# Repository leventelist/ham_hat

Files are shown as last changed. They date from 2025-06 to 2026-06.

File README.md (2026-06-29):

# Raspberry PI hat for radio amateurs

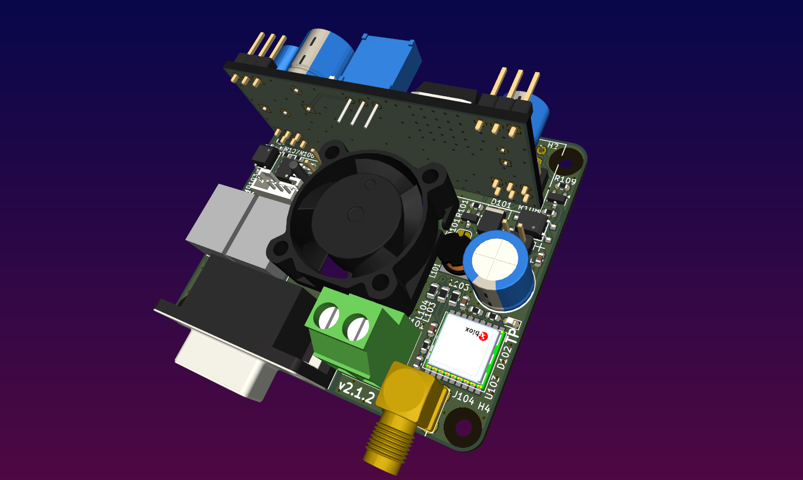
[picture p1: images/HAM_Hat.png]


## History

I've been doing a lot of SOTA activations with Raspberry PI like SBCs, and there
where always issues, like RF interference, and power supply shorts. I started to
add things like galvanically decoupled audio interface, a step down power supply. It
was working, but it looked like a mess.

This piece of hardware integrates all needed equipment in one nice hat. It is designed
to put the RPI in a metallic box to further isolate from RF signals.

It was designed using [KiCad](https://www.kicad.org/).

## Applications

* HF/VHF digital modes (PSK, FT8, etc)
* HF/VHF AX.25 based modes (Packet, APRS, etc)
* CW keying
* Clock synchronization
* Position tracking

## Features

 * 3A power supply with wide input voltage range: 8 to 35V
 * Ublox MAX-8/10 GPS receiver for position and time synchronization
 * Inductive audio couplers to minimize GND loops. Up to 4kHz.
 * PWM controlled cooling fan
 * GPIO controlled PTT from the PI
 * GPIO controlled CW key from the PI
 * RTC
 * Shutdown button
 * Run LED

GPS antenna is not integrated in the device, so an external antenna connector is
mounted on the PCB.

Ufortunately, the sound card of the PI can not record audio, so an
external sound card must be used. I use
[this](https://www.axagon.eu/en/produkty/ada-17) particular device with good
results. I usually break the plastic housing, and solder a shielded cable
directly to the audio interface (J109).

The GPS is needed for APRS and time synchronization. There is an onbard RTC to have some redundancy.

## Placing variants

There are a few components that mounted or unmounted depending on particular application.

### HT radio

When this device is used with a handheld radio, that has a PTT and mic input (Like the FT-4X), mount C108 and R116. Please note that the value of R116 might vary based on the actual transceiver used.

If used with a radio that has separate input for audio and PTT, mount a 0 Ohm resistor to C108. You might also leave C108 as a capacitor (22uF), but it is not really needed.

C108 and R116 is placed on the layout that it can be mounted or replaced after everything else is mounted too. All you need is the dismount tha cooling fan.

### High bandwidth audio

If you want to have direct access to the audio interface of your radio, you can leave T101 and T102 unpopulated and short JP102 and JP103, JP104. Please note that you will loose GND separation as well.

## Mechanics

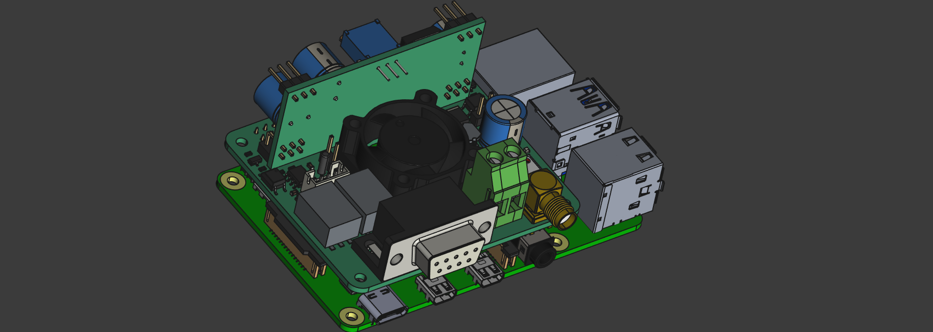
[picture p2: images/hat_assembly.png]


It is designed to fit on the Raspberry PI 4. Be aware, that if the heatsink on the CPU is too high, it might
conflict with the screws of the fan. If that happens, mount the heatsink 45 degrees.

### Box

A box is designed in FreeCAD using sheets of PCB. The idea is to use bare, one sided PCBs, and solder the plates from the inside. The sheets can be easily milled by a CNC machine.

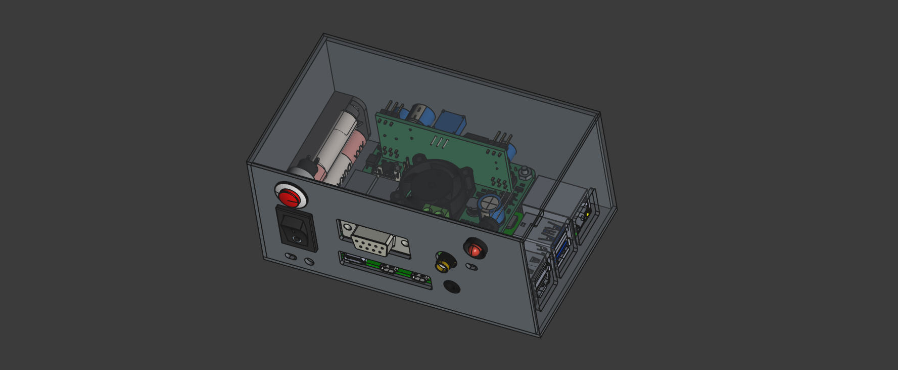
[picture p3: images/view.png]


There are several cutouts on the box.

In the front, you have the power inlet, and a second cutout for powering the attached LCD screen. On the right side of the front sheet, there is a cutout for the power chord to the GPS antenna, if needed.

On the right, there are anouther cutout for the audio cable.

The assembly does not include some (all) the models, hence they might violate copyright.

## Connection to the radio

The hat comes with a DB9 connector to connect up your rig. I wanted to have a screw lock
connector, and this was the best choice. The pin out looks like this.

| Signal name | Pin of the DB9 | Comment |
|---|---|---|
| TX audio | 1 | Audio input of your rig  |
| KEY | 2 | CW key of the rig |
| PTT | 3 | PTT input of your rig |
| NC | 4 | Not connected |
| RX audio | 5 | Audio output of your rig |
| GND | 6 | Audio ground |
| GND | 7 | Audio ground |
| GND | 8 | Audio ground |
| GND | 9 | Audio ground |

### GPIO connections

| Signal name | GPIO | Commnet |
|---|---|---|
| PTT | 12 | |
| KEY | 21 | |
| DCD | 16 | |

## Connection to the soundcard

J105 provides connection to the soundcard.

| Signal name | Pin of J105 | Comment |
|---|---|---|
| RX audio | 1 | Mic input of your soundcard |
| TX audio | 4 | Speaker output of your soundcard |
| GND | 2,3 | Audio ground |

## Power connection

J101 provides power connection. The maximum input voltage is 35Volts.

## GPS

Use u-blox MAX-8C/Q or MAX-M10S GNSS module. When the MAX-10 is used, don't populate R113.

Connect your passive or active GPS antenna to J104. Use 3.3V active antenna. PPS signal is provided on GPIO18.

When passive antenna is used, don't populate L102.

[Here](https://austinsnerdythings.com/2021/04/19/microsecond-accurate-ntp-with-a-raspberry-pi-and-pps-gps/) is an excellent article how to set up GPIO-PPS for ntpd.

## RTC

BQ32000 based precision RTC is provided for backup if the GPS can't provide accurate timing.

### Enable I²C on Raspberry Pi
```bash
sudo raspi-config
```
Navigate to:
```
Interfacing Options → I2C → Enable
```
Reboot the Raspberry Pi:
```bash
sudo reboot
```

### Check I²C Communication
```bash
sudo apt install i2c-tools
i2cdetect -y 1
```
You should see the RTC at **0x68**.

### Configure Linux to Use BQ32000
```bash
sudo modprobe rtc-bq32k
echo bq32000 0x68 | sudo tee /sys/class/i2c-dev/i2c-1/device/new_device

# This next one line only needed to set initial time of the RTC
# Otherwise it'll fail to read
sudo hwclock -w

# Test to read the RTC
sudo hwclock -r
```

### Make It Persistent
Edit `/boot/firmware/config.txt`:

Add the following line:
```
dtoverlay=i2c-rtc,bq32000
```
Save and reboot:
```bash
sudo reboot
```

### Disable Fake RTC (if needed)
```bash
sudo systemctl disable fake-hwclock
sudo systemctl stop fake-hwclock
```
Edit `/lib/udev/hwclock-set` and comment out:
```bash
#if [ -e /run/systemd/system ] ; then
#    exit 0
#fi
```
```bash
apt remove fake-hwclock
```

### Create a systemd service to set system clock from RTC

/etc/systemd/system/rtc-sync.service

The content of this file attached.

### Sync RTC with System Time
Set RTC from system time:
```bash
sudo hwclock -w
```
Set system time from RTC:
```bash
sudo hwclock -s
```

### Final Test
Check that the RTC retains the time after reboot:
```bash
sudo hwclock -r
```

Connect a 3V battery to BT101 for offline RTC operation.

## FAN control

PWM shall be enabled on GPIO13.

If you don't want PWM control, short JP101, and the fan will spin at full power all times.

There's a non-PWM control of the fan that works out of the box using the Raspberry PI OS.

Open raspi-config, under Performance Options, you shall select the desired temperature,
and the GPIO pin which is 13.

## Shutdown button can be connected to J106

To make it work, you have to add these lines to /boot/firmware/config,txt

```
dtoverlay=gpio-shutdown,gpio_pin=26
```

Ther's also a LED (D107 )that shines when the system is running. When it
Doesn't, it is safe to remove power from the RPI.

To make this work, add this too:

```
dtoverlay=gpio-poweroff,gpiopin=7,active_low=1
```

## Accessories

These items needed for the hat for full functionality.

All sourced from [Farnell](https://www.farnell.com/), unless othervise noted. (Sorry, I'm Hungary based.)

| Item | Source designator | Comment |
|---|---|---|
| RTC Battery | 1892670 | The idea is to use heatshrink tube and some wires. |
| RTC Battery holder | 3583203 | External battery holder for CR2032 |
| Heatsink | 1211701 or https://www.alza.hu/raspberry-pi-rb-hutoborda-d4147799.htm?o=21 ||
| Standoff | 1466844 | It must be 12mm in length |
| Mounting screws M2.5x6 | | |
| GPS antenna | [This](https://www.soselectronic.hu/products/2j/2j431gmp-250rg174-c20n-173902) or [this](https://www.soselectronic.hu/products/2j/2j0801b-c814g-217598) | Use 3V active antenna |
| RPI4 | 3369503 (8GB) or 3051887 (4GB) | |
| USB audio interface| [Alza](https://www.alza.hu/axagon-ada-10-mini-d1470921.htm) | Any other do the job. Check Linux driver availability. |
| Monitor| [Ebay](https://www.ebay.com/itm/353758771148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)
| Keyboard | https://www.pcland.hu/genius-luxemate-100-usb-fekete-hun-billentyuzet-31300725113 | Any USB Keyboard. I use the one without keypad, for its compact size. |
| Mice | | Any USB, or BLE mice |
| SD card with Raspbian image. | | |
| uHDMI to HDMI cable | [Alza](https://www.alza.hu/vention-micro-hdmi-to-hdmi-cable-2m-black-d5891200.htm?o=1) | |
| DB9 Male connector | | To connect to your radio |
| Data connector for your radio |
| Shielded audio cable | | To connect the soundcard to the hat, and for the DB9 connector |

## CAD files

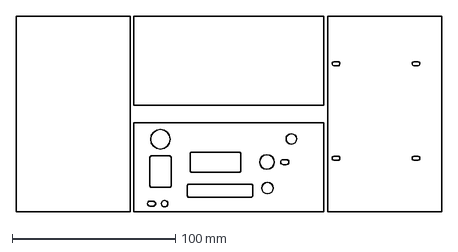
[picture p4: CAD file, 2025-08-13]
box/CNC/integrated/large_parts.dxf
261.0 x 120.0 mm

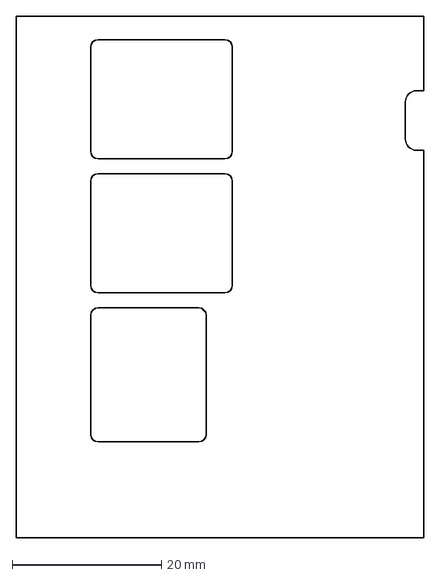
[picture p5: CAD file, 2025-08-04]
box/CNC/rpi4_case_base-right.dxf
54.7 x 70.0 mm

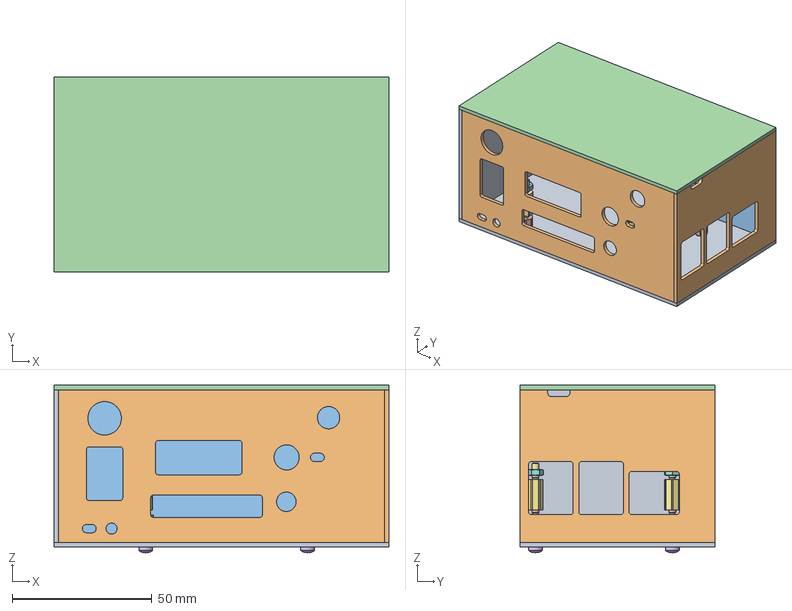
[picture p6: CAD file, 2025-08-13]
box/rpi4_case_base.FCStd
120.0 x 70.0 x 60.0 mm
base
front
back
top
M2.5x10x5-Standoff x 4
M2.5x6-Screw x 4
M2.5x11x5-Standoff x 4
M2.5-Nut x 4
left
right

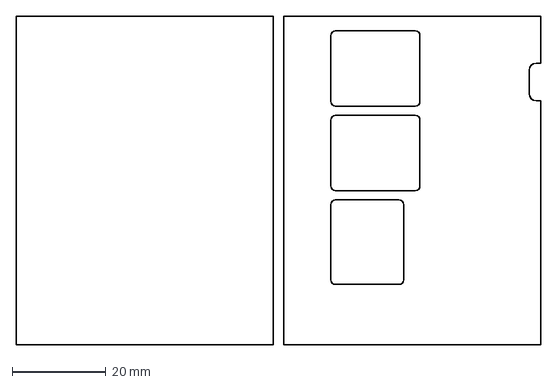
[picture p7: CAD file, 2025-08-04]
box/CNC/integrated/small_parts.dxf
111.7 x 70.0 mm

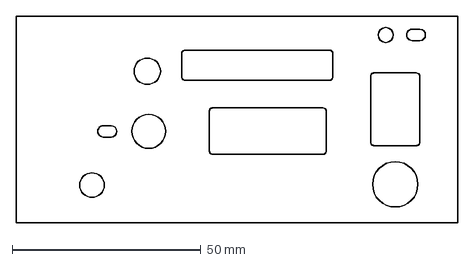
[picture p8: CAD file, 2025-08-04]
box/CNC/rpi4_case_base-front.dxf
116.7 x 54.7 mm

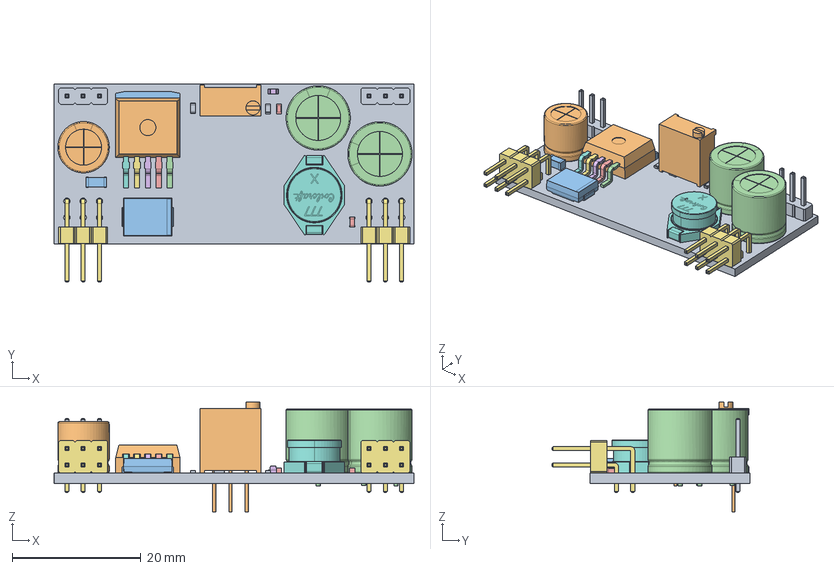
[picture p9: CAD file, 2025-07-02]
box/SMPS3A.FCStd
56.0 x 30.8 x 17.1 mm
Pcb_f4e0
C101_CP_Radial_D80mm_P350mm_00005b5bec9b
C102_C_1206_3216Metric_00005b5bed43
C103_CP_Radial_D100mm_P500mm_00005b5bed53 x 2
C104_C_0603_1608Metric_00005b5bee1e x 2
D102_LED_0603_1608Metric_00005b5bef20
J101_PinHeader_2x03_P254mm_Horizontal_00005b5bef32 x 2
L102_Coilcraft-DO3316P_00005b5befd3
R101_R_0603_1608Metric_00005b5befde x 3
a648ce37-9c39-11ed-93f0-dde97e994e83_part
a648ce38-9c39-11ed-93f0-dde97e994e83_part
a648ce39-9c39-11ed-93f0-dde97e994e83_part
a648ce39-9c39-11ed-93f0-dde97e994e83_part001
a648ce39-9c39-11ed-93f0-dde97e994e83_part002
a648ce39-9c39-11ed-93f0-dde97e994e83_part003
a648ce39-9c39-11ed-93f0-dde97e994e83_part004
J103_PinHeader_1x03_P254mm_Vertical_00005b5cb08c x 2
RV101_Potentiometer_Bourns_3296W_Vertical_00005fe729f7
D101_D_SMC_0000611d8a5b

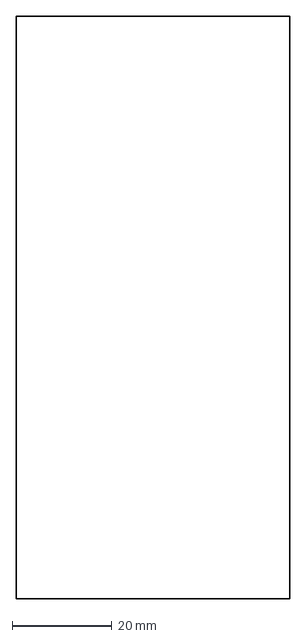
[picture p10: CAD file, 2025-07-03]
box/CNC/rpi4_case_base-back.dxf
54.7 x 116.7 mm

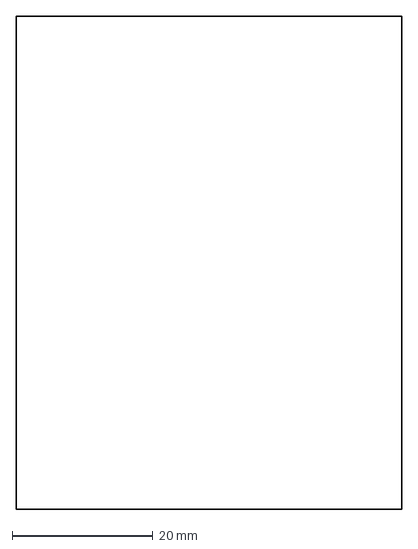
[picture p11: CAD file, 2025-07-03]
box/CNC/rpi4_case_base-left.dxf
54.7 x 70.0 mm

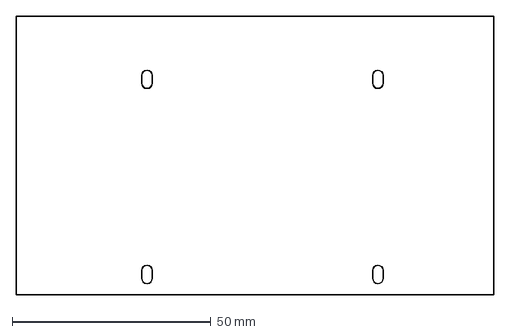
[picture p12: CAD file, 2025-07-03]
box/CNC/rpi4_case_base-base.dxf
120.0 x 70.0 mm

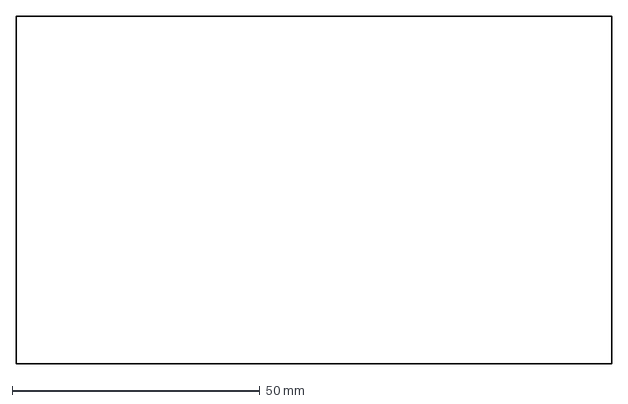
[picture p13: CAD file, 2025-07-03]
box/CNC/rpi4_case_base-top.dxf
120.0 x 70.0 mm

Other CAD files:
assembly/hat_assembly.FCStd

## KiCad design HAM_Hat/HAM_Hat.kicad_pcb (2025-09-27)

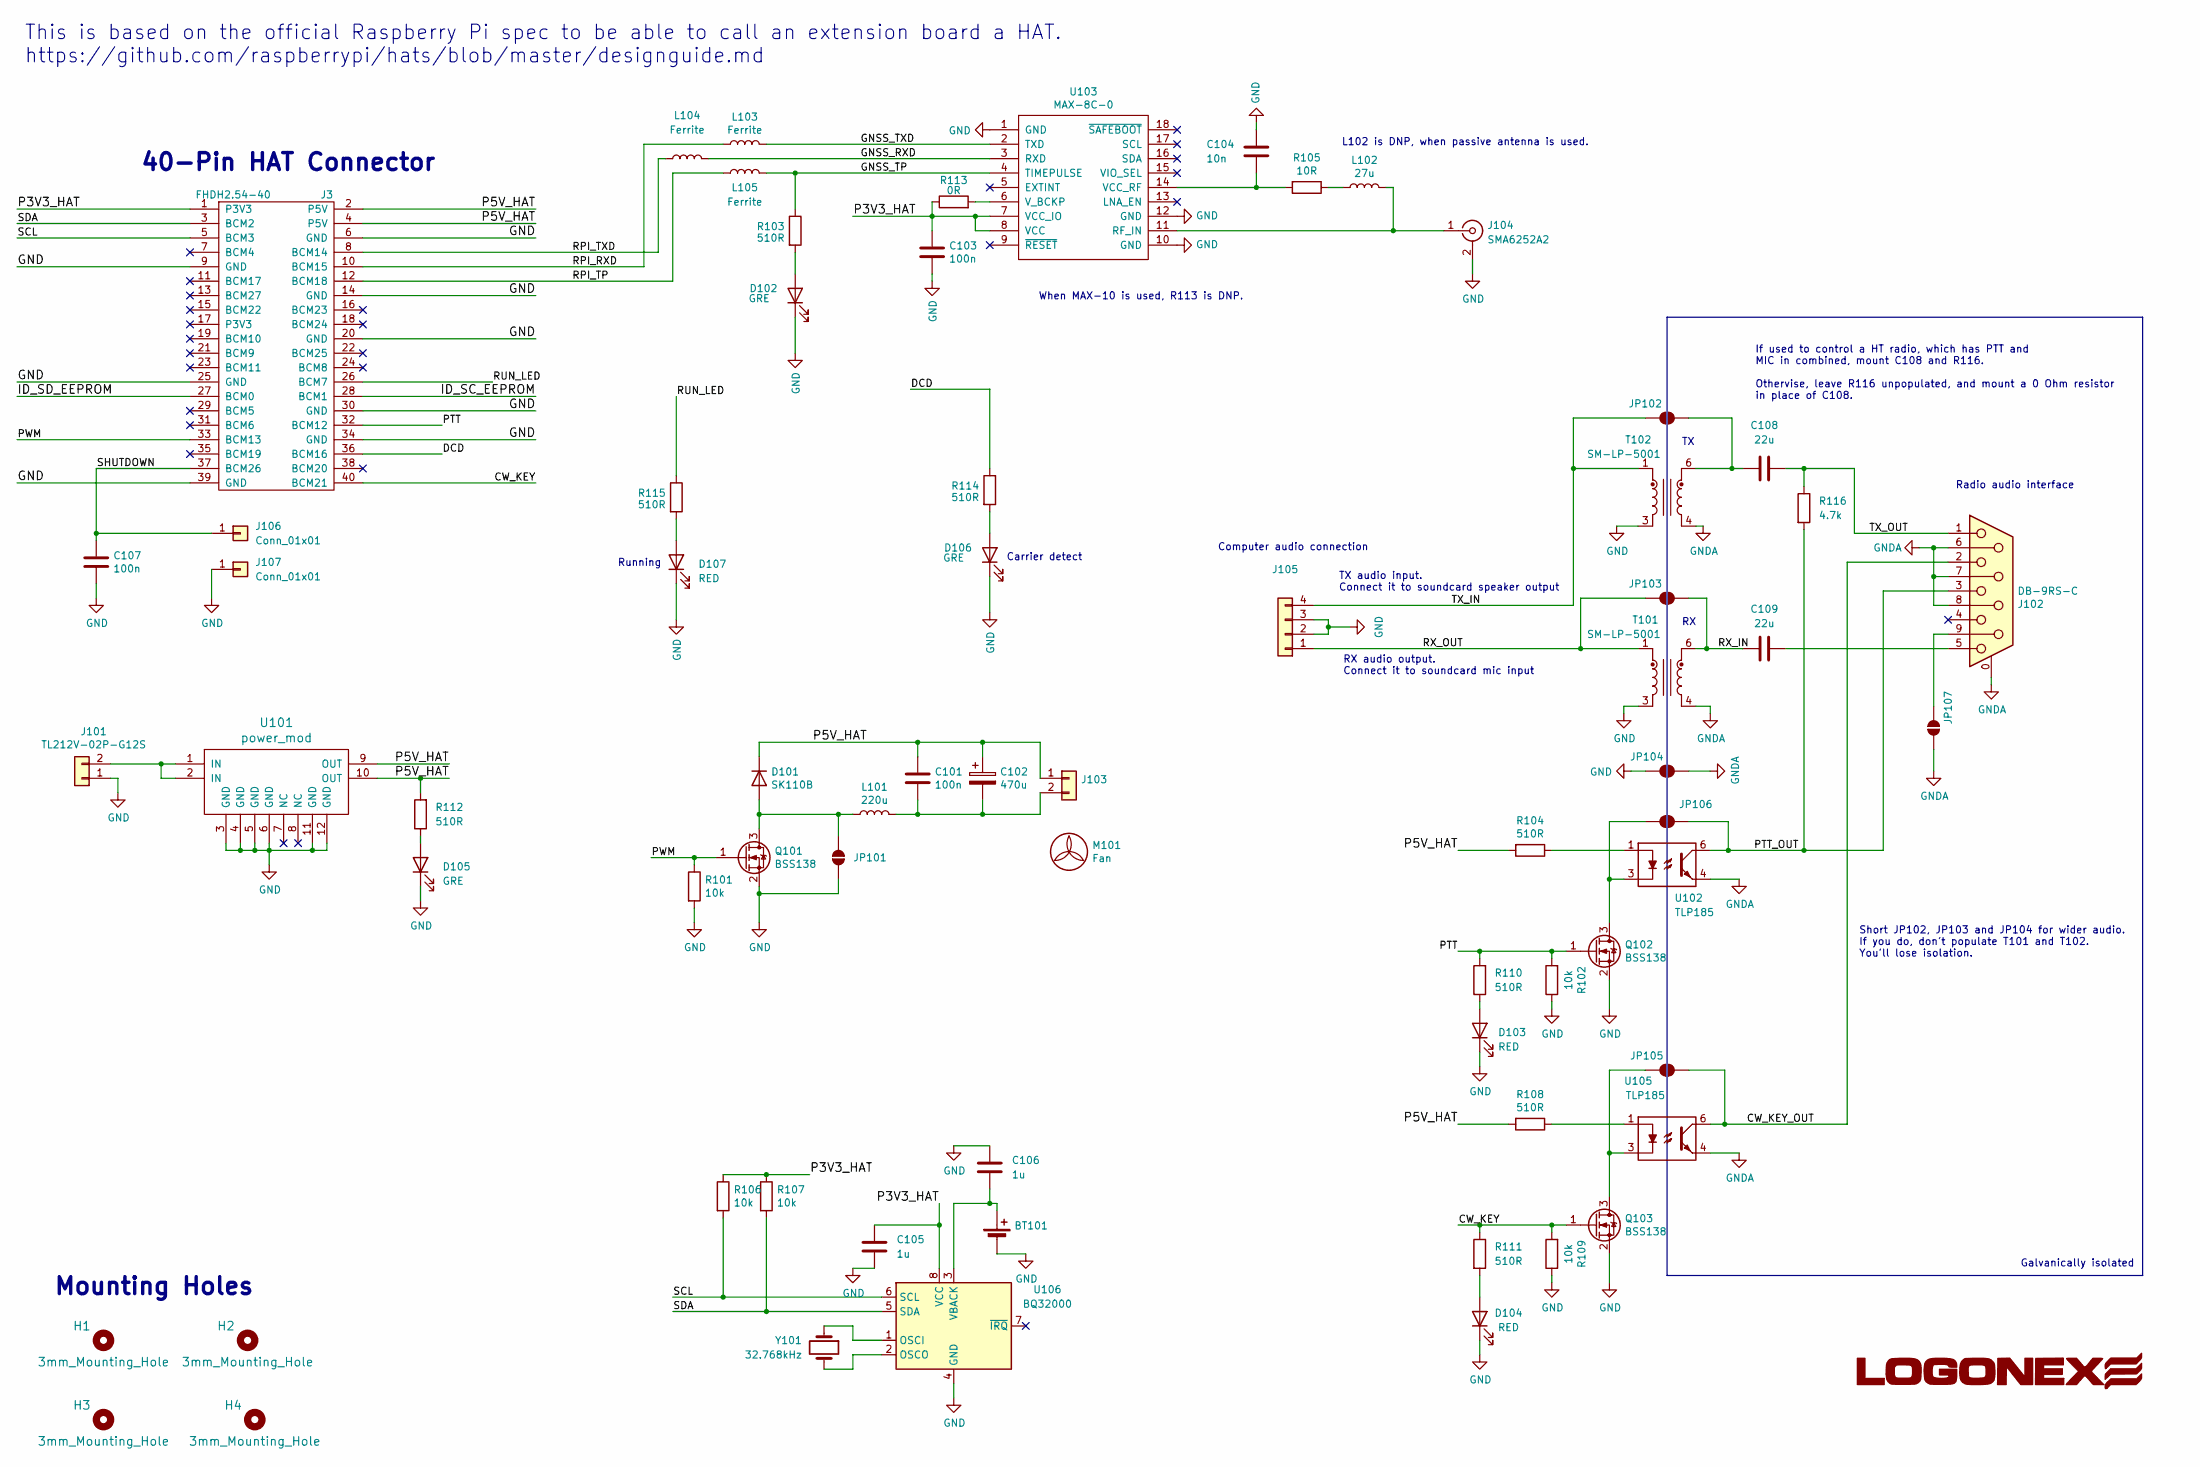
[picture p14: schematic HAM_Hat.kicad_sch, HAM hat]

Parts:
BT101: PinHeader_2x01_P2.54mm_Vertical
C101, C103, C107: 100n; C_0603_1608Metric
C102: 470u; CP_Radial_D10.0mm_P5.00mm
C104: 10n; C_0603_1608Metric
C105, C106: 1u; C_0603_1608Metric
C108, C109: 22u; C_1206_3216Metric
D101: SK110B; D_SMB
D102, D105, D106: GRE; LED_0603_1608Metric
D103, D104, D107: RED; LED_0603_1608Metric
H1, H2, H3, H4: 3mm_Mounting_Hole; l_MountingHole_Clear_2.75mm_M2.5
J3: FHDH2.54-40; PinSocket_2x20_P2.54mm_Vertical
J101: TL212V-02P-G12S; TerminalBlock-2-5.0_1x02_P5.0mm_Horizontal
J102: DB-9RS-C; DSUB-9_Female_Horizontal_P2.77x2.84mm_EdgePinOffset7.70mm_H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
J103: PinHeader_1x02_P2.54mm_Vertical
J104: SMA6252A2; SMA_angled
J105: PinHeader_1x04_P2.54mm_Vertical
J106, J107: Conn_01x01; SolderWirePad_1x01_SMD_2x5mm
JP101, JP102, JP103, JP104, JP105, JP106, JP107: SolderJumper_2_Open; SolderJumper-2_P1.3mm_Open_RoundedPad1.0x1.5mm
L101: 220u; IND_PCD0504
L102: 27u; L_0603_1608Metric
L103, L104, L105: Ferrite; R_0805_2012Metric
M101: Fan; 25x25
Q101, Q102, Q103: BSS138; SOT-23
R101, R102, R106, R107, R109: 10k; R_0603_1608Metric
R103, R104, R108, R110, R111, R112, R114, R115: 510R; R_0603_1608Metric
R105: 10R; R_0603_1608Metric
R113: 0R; R_0603_1608Metric
R116: 4.7k; R_0603_1608Metric
T101, T102: SM-LP-5001; SM_LP_5001
U101: power_mod; power_mod3A
U102, U105: TLP185; 11-4M1S
U103: MAX-8C-0; MAX8
U106: BQ32000; SOIC-8_3.9x4.9mm_P1.27mm
Y101: 32.768kHz; Crystal_DS26_D2.0mm_L6.0mm_Vertical

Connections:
/CW_KEY: J3.40 (BCM21), Q103.1 (G), R109.2, R111.1
/CW_KEY_OUT: J102.2, JP105.2 (B), U105.6
/DCD: J3.36 (BCM16), R114.1
/GNSS_RXD: L104.2, U103.3 (RXD)
/GNSS_TP: L105.2, R103.1, U103.4 (TIMEPULSE)
/GNSS_TXD: L103.2, U103.2 (TXD)
/ID_SC_EEPROM: J3.28 (BCM1)
/ID_SD_EEPROM: J3.27 (BCM0)
/P3V3_HAT: C103.1, C105.1, J3.1 (P3V3), R106.1, R107.1, R113.1, U103.7 (VCC_IO), U103.8 (VCC), U106.8 (VCC)
/P5V_HAT: C101.1, C102.1, D101.1 (K), J3.2 (P5V), J3.4 (P5V), J103.1, R104.2, R108.2, R112.2, U101.9 (OUT), U101.10 (OUT)
/PTT: J3.32 (BCM12), Q102.1 (G), R102.2, R110.2
/PTT_OUT: J102.3, JP106.2 (B), R116.2, U102.6
/PWM: J3.33 (BCM13), Q101.1 (G), R101.1
/RPI_RXD: J3.10 (BCM15), L103.1
/RPI_TP: J3.12 (BCM18), L105.1
/RPI_TXD: J3.8 (BCM14), L104.1
/RUN_LED: J3.26 (BCM7), R115.1
/RX_IN: C109.2, JP103.2 (B), T101.6
/RX_OUT: J105.1, JP103.1 (A), T101.1
/SCL: J3.5 (BCM3), R106.2, U106.6 (SCL)
/SDA: J3.3 (BCM2), R107.2, U106.5 (SDA)
/SHUTDOWN: C107.1, J3.37 (BCM26), J106.1
/TX_IN: J105.4, JP102.1 (A), T102.1
/TX_OUT: C108.2, J102.1, R116.1
GND: BT101.2 (-), C103.2, C104.1, C105.2, C106.1, C107.2, D102.1 (K), D103.1 (K), D104.1 (K), D105.1 (K), D106.1 (K), D107.1 (K), J3.6 (GND), J3.9 (GND), J3.14 (GND), J3.20 (GND), J3.25 (GND), J3.30 (GND), J3.34 (GND), J3.39 (GND), J101.1, J104.2 (Ext), J105.2, J105.3, J107.1, JP101.2 (B), JP104.1 (A), Q101.2 (S), Q102.2 (S), Q103.2 (S), R101.2, R102.1, R109.1, T101.3, T102.3, U101.3 (GND), U101.4 (GND), U101.5 (GND), U101.6 (GND), U101.11 (GND), U101.12 (GND), U103.1 (GND), U103.10 (GND), U103.12 (GND), U106.4 (GND)
GNDA: J102.0 (PAD), J102.6, J102.7, J102.8, JP104.2 (B), JP107.2 (B), T101.4, T102.4, U102.4, U105.4
unnamed: BT101.1 (+), C106.2, U106.3 (VBACK)
unnamed: C109.1, J102.5
unnamed: D101.2 (A), JP101.1 (A), L101.1, Q101.3 (D)
unnamed: D102.2 (A), R103.2
unnamed: D103.2 (A), R110.1
unnamed: D104.2 (A), R111.2
unnamed: D105.2 (A), R112.1
unnamed: D106.2 (A), R114.2
unnamed: D107.2 (A), R115.2
unnamed: J101.2, U101.1 (IN), U101.2 (IN)
unnamed: C101.2, C102.2, J103.2, L101.2
unnamed: J104.1 (In), L102.2, U103.11 (RF_IN)
unnamed: C108.1, JP102.2 (B), T102.6
unnamed: JP105.1 (A), Q103.3 (D), U105.3
unnamed: JP106.1 (A), Q102.3 (D), U102.3
unnamed: J102.9, JP107.1 (A)
unnamed: L102.1, R105.1
unnamed: R104.1, U102.1
unnamed: R108.1, U105.1
unnamed: C104.2, R105.2, U103.14 (VCC_RF)
unnamed: R113.2, U103.6 (V_BCKP)
unnamed: U106.1 (OSCI), Y101.1
unnamed: U106.2 (OSCO), Y101.2

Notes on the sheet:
Carrier detect
When MAX-10 is used, R113 is DNP.
This is based on the official Raspberry Pi spec to be able to call an extension board a HAT. https://github.com/raspberrypi/hats/blob/master/designguide.md
Radio audio interface
If used to control a HT radio, which has PTT and MIC in combined, mount C108 and R116. Othervise, leave R116 unpopulated, and mount a 0 Ohm resistor in place of C108.
Galvanically isolated
L102 is DNP, when passive antenna is used.
Short JP102, JP103 and JP104 for wider audio. If you do, don't populate T101 and T102. You'll lose isolation.
Mounting Holes
RX audio output. Connect it to soundcard mic input
40-Pin HAT Connector
TX audio input. Connect it to soundcard speaker output
Computer audio connection
Running

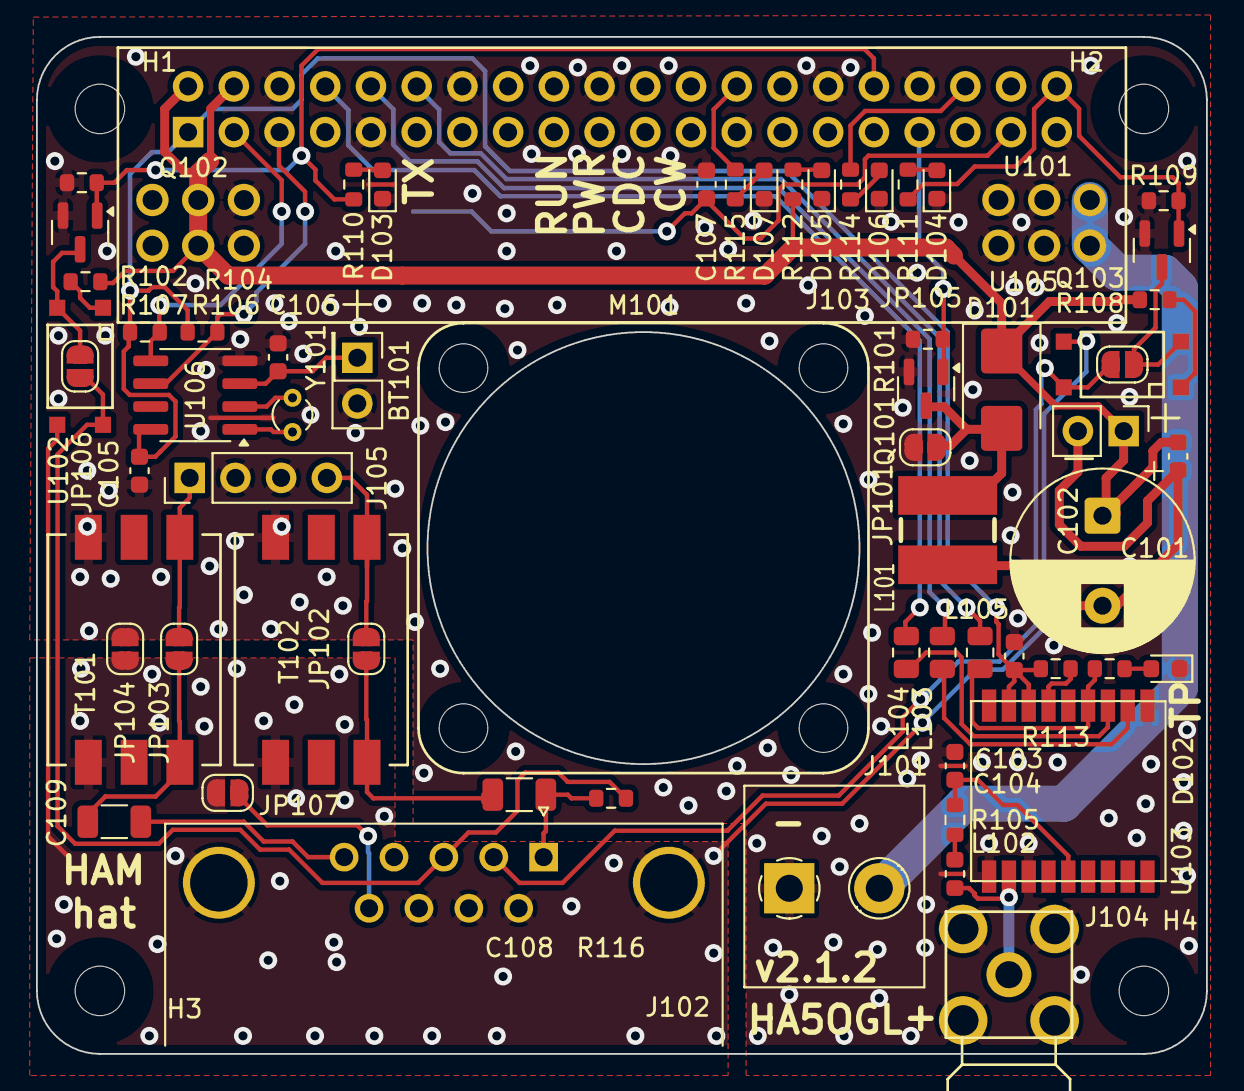
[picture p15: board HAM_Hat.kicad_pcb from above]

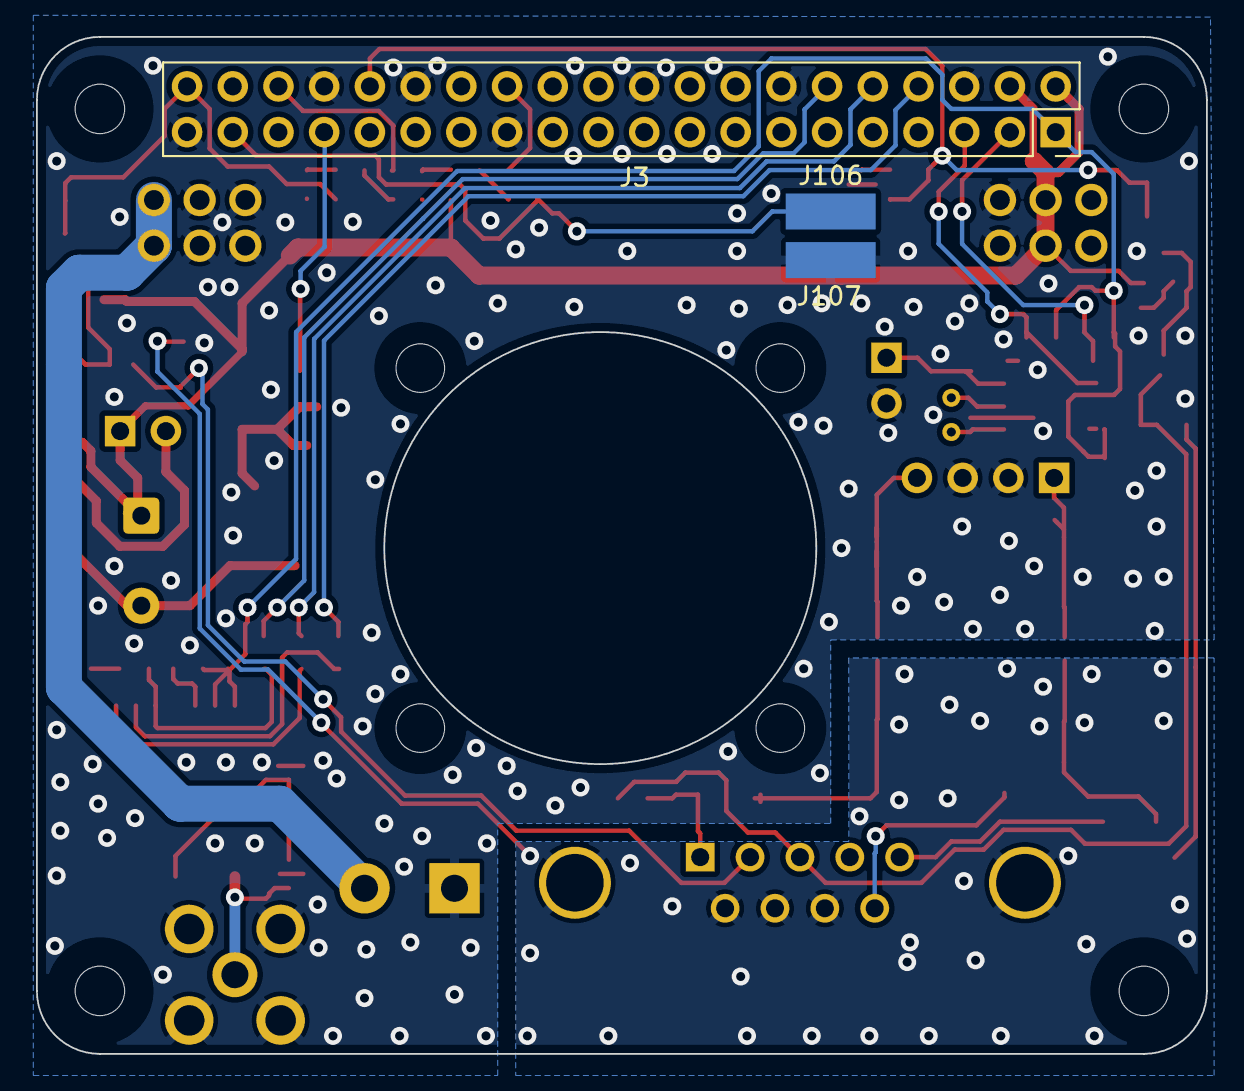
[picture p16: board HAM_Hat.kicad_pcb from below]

Board: 2 copper layers, 65.0 x 56.5 mm, 69 parts (3 on the bottom side), 47 nets.

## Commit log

2021-11-30 Some progress on the layout
    [HAM_Hat.kicad_pcb]
2021-12-01 0 unconnect
    [HAM_Hat.kicad_pcb, HAM_Hat.sch]
2021-12-02 Release candidate
    [.bumpversion.cfg, HAM_Hat.kicad_pcb]
2021-12-02 Title block
    [HAM_Hat.kicad_pcb, HAM_Hat.sch]
2021-12-02 Bump version: 0.0.0 → 1.0.0
    [.bumpversion.cfg, HAM_Hat.kicad_pcb, HAM_Hat.sch]
2021-12-03 Documentation update
    [HAM_Hat.kicad_pcb, HAM_Hat.sch, HAM_Hat_bom.csv]
2021-12-03 Add BOM
    [HAM_Hat_bom.csv]
2021-12-03 DE9 pinout change
    [HAM_Hat.kicad_pcb, HAM_Hat.sch]
2021-12-04 Some more ideas. Thanks John WB2OSZ!
    [HAM_Hat.kicad_pcb, HAM_Hat.sch]
2021-12-04 Schematic update
2021-12-04 Bump version: 1.0.0 → 1.0.1
    [.bumpversion.cfg, HAM_Hat.kicad_pcb, HAM_Hat.sch]
2021-12-04 Fix outline
    [HAM_Hat.kicad_pcb]
2021-12-04 Fix mechanical collisions with the PI
    [HAM_Hat.kicad_pcb]
2021-12-04 Bump version: 1.0.1 → 1.0.2
    [.bumpversion.cfg, HAM_Hat.kicad_pcb, HAM_Hat.sch]
2021-12-04 Add some notes about the fan.
2021-12-04 Some optiomization
    [HAM_Hat.kicad_pcb]
2021-12-04 Bump version: 1.0.2 → 1.0.3
    [.bumpversion.cfg, HAM_Hat.kicad_pcb, HAM_Hat.sch]
2021-12-04 New assembly
2021-12-04 More fixes
    [HAM_Hat.kicad_pcb]
2021-12-05 Add RTC
    Also add header socket for audio connection.
    [HAM_Hat.kicad_pcb, HAM_Hat.sch]
2021-12-05 Add RTC
    Audio connection replaced by a header socket.
    [HAM_Hat.kicad_pcb, HAM_Hat.sch, HAM_Hat_bom.csv]
2021-12-05 Bump version: 1.0.3 → 1.0.4
    [.bumpversion.cfg, HAM_Hat.kicad_pcb, HAM_Hat.sch]
2021-12-08 Add 4pin header into BoM
    [HAM_Hat.sch, HAM_Hat_bom.csv]
2023-01-16 Migrate to KiCad v7
    [HAM_Hat.kicad_sch, HAM_Hat.sch]
2023-01-20 3D models added
    [HAM_Hat.kicad_pcb]
2023-01-20 Replace the DB9 connector
    [HAM_Hat.kicad_pcb, HAM_Hat.kicad_sch]
2023-01-21 Add CW keying function
    [HAM_Hat.kicad_pcb, HAM_Hat.kicad_sch]
2023-01-22 Some progress on the CW keying support
    [HAM_Hat.kicad_pcb]
2023-01-23 CW keying added
    [HAM_Hat.kicad_pcb]
2023-01-23 Mounting holes changed
    [HAM_Hat.kicad_pcb, HAM_Hat.kicad_sch, HAM_Hat_bom.csv]
2023-01-23 Update documentation
    [HAM_Hat.kicad_sch]
2023-01-23 Bump version: 1.0.4 → 1.1.0
    [.bumpversion.cfg, HAM_Hat.kicad_pcb, HAM_Hat.kicad_sch]
2023-04-05 KiCad file format update
    [HAM_Hat.kicad_sch]
2023-04-05 Connect more GND to the connector
    [HAM_Hat.kicad_pcb, HAM_Hat.kicad_sch]
2023-04-05 Add 0.5mm edge clearence to copper.
    [HAM_Hat.kicad_pcb]
2023-04-05 Minor issues fixed
    [HAM_Hat.kicad_pcb]
2024-03-29 Migration to KiCad v8.0.1
    [HAM_Hat.kicad_pcb, HAM_Hat.kicad_sch]
2024-08-29 Remove the potmeters. Add more robust connector
    [HAM_Hat.kicad_pcb, HAM_Hat.kicad_sch]
2024-08-29 New schematic
2024-12-29 Add LEDs to CW and PTT lines
    Rotate the GPS module
    [HAM_Hat.kicad_pcb, HAM_Hat.kicad_sch]
2024-12-31 Add u.fl connector instead of the SMA
    [HAM_Hat.kicad_pcb, HAM_Hat.kicad_sch]
2025-01-02 Add power LED
    [HAM_Hat.kicad_pcb, HAM_Hat.kicad_sch]
2025-01-02 Bump version: 1.1.0 → 2.0.0
    [.bumpversion.cfg, HAM_Hat.kicad_pcb, HAM_Hat.kicad_sch]
2025-01-11 U.FL connector replace
    Migration to Kicad v9
    [HAM_Hat.kicad_pcb, HAM_Hat.kicad_sch]
2025-02-01 Minor changes
    [HAM_Hat.kicad_pcb]
2025-02-01 Change the RTC to some cheeper one
    [HAM_Hat.kicad_pcb, HAM_Hat.kicad_sch]
2025-04-13 PS footprint update
    [HAM_Hat.kicad_pcb]
2025-04-13 Version number moved
    [HAM_Hat.kicad_pcb]
2025-04-13 Move texts
    [HAM_Hat.kicad_sch]
2025-04-13 Bump version: 2.0.0 → 2.0.1
    [.bumpversion.cfg, HAM_Hat.kicad_pcb, HAM_Hat.kicad_sch]
2025-04-28 Add DCD LED
    [HAM_Hat.kicad_pcb, HAM_Hat.kicad_sch]
2025-04-28 Bump version: 2.0.1 → 2.1.0
    [.bumpversion.cfg, HAM_Hat.kicad_pcb, HAM_Hat.kicad_sch]
2025-04-30 LED moved
    [HAM_Hat.kicad_pcb, HAM_Hat.kicad_sch]
2025-04-30 Alternative LED positions
    [HAM_Hat.kicad_pcb, HAM_Hat.kicad_sch]
2025-04-30 Bump version: 2.1.0 → 2.1.1
    [.bumpversion.cfg, HAM_Hat.kicad_pcb, HAM_Hat.kicad_sch]
2025-05-09 Add shutdown switch interface
    [HAM_Hat.kicad_pcb, HAM_Hat.kicad_sch]
2025-05-10 Add run LED
    [HAM_Hat.kicad_pcb, HAM_Hat.kicad_sch]
2025-05-10 Add Shutdown button and Run LED doc
2025-05-10 Remove schematic plot
    [HAM_Hat_bom.csv]
2025-05-10 PCB: FIX DRC warnings. Also updated footprints
    [HAM_Hat.kicad_pcb]
2025-05-19 Rearrange GPS. Possibly better performance
    [HAM_Hat.kicad_pcb]
2025-05-19 Bump version: 2.1.1 → 2.1.2
    [.bumpversion.cfg, HAM_Hat.kicad_pcb, HAM_Hat.kicad_sch]
2025-07-01 Some change on the assembly
    [hat_assembly.FCStd]
2025-07-01 Add box
    This needs to be redone.
    [rpi4_case_base.FCStd]
2025-07-02 Add assembly
    [SMPS3A.FCStd, rpi4_case_base.FCStd]
2025-07-03 Modify cutout for power chord
    [rpi4_case_base.FCStd]
2025-07-03 Add CNC files
    [large_parts.dxf, rpi4_case_base-back.dxf, rpi4_case_base-base.dxf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]
2025-07-08 Add battery holder
    [rpi4_case_base.FCStd]
2025-07-08 Add cutout for audio cable
    This makes the model broken.
    [rpi4_case_base.FCStd]
2025-07-08 Add the assembly rendering
2025-08-03 Add shutdown button to the box
    [rpi4_case_base.FCStd]
2025-08-04 Replace the 2mm pitch connector to 2.54mm pitch
    This is not really a connector, rather then a pads to
    solder wires.
    [HAM_Hat.kicad_pcb, HAM_Hat.kicad_sch]
2025-08-04 Update DXF exports
    [large_parts.dxf, rpi4_case_base-front.dxf, rpi4_case_base-right.dxf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]
2025-08-04 Explode objects
    [large_parts.dxf, small_parts.dxf]
2025-08-04 Removed redundant lines
    [large_parts.dxf]
2025-08-10 Add HT radio option
    [HAM_Hat.kicad_pcb, HAM_Hat.kicad_sch]
2025-08-13 Fix some issues
    [large_parts.dxf, rpi4_case_base.FCStd]
2025-08-15 Move shutdown connector
    [HAM_Hat.kicad_pcb, HAM_Hat.kicad_sch]
2025-09-27 Add DC decoupling capactiors
    [HAM_Hat.kicad_pcb, HAM_Hat.kicad_sch]
